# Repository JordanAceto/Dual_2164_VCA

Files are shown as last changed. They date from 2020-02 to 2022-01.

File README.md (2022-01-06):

# SSI2164 based dual VCA PCB



## [SCHEMATIC](https://github.com/JordanAceto/Dual_2164_VCA/blob/master/main_pcb/construction_docs/dual_VCA_schematic.pdf)

## Features:
- Two independent linear VCAs
- Manual offset controls
- Attenuated CV inputs
- Unity gain at +5 volts CV
- AC/DC coupling selected by solder jumper
- Designed to either use board mounted pots and jacks which affix directly to a panel, or mount to a bracket and wire by hand
- There is a 10hp pcb front panel, for a cheap and cheerful panel option.

## Status of the project:

Task | Status |
---------|--------------|
Schematic capture | &#9745;
PCB layout | &#9745;
Test build | &#9745;
Safe to order boards| &#9745;

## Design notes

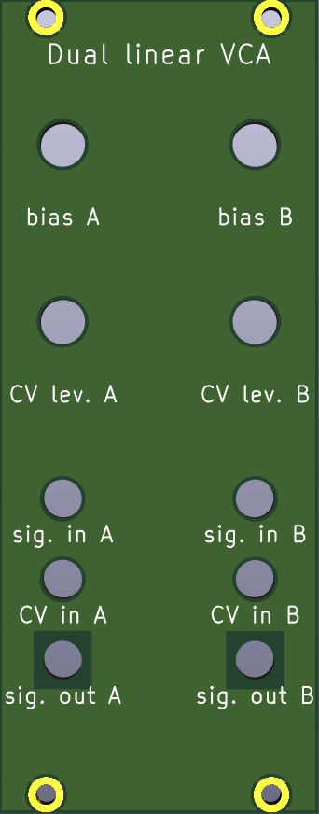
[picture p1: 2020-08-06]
front_panel/pics/front_panel.png

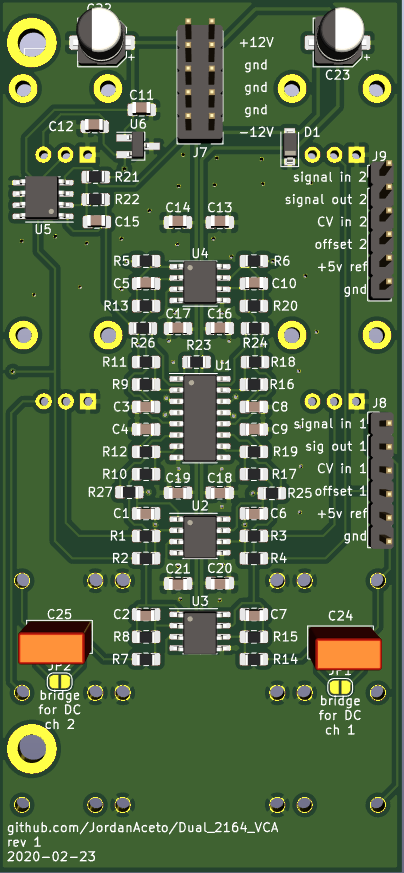
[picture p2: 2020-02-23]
main_pcb/pics/pcb_rear.png

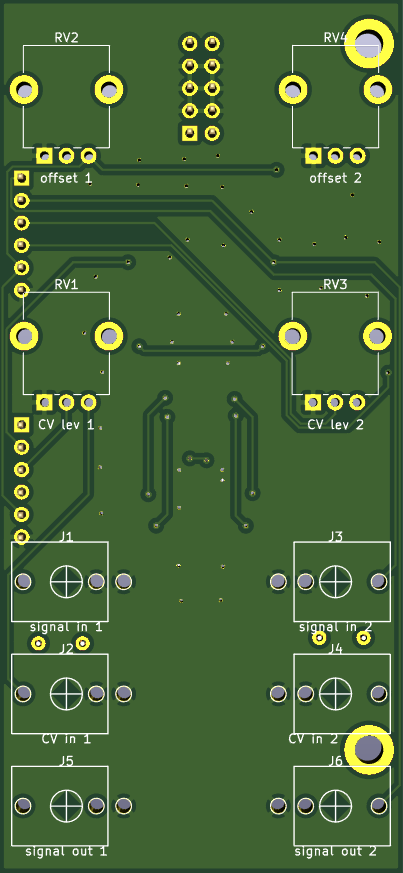
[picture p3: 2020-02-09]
main_pcb/pics/pcb_front.png

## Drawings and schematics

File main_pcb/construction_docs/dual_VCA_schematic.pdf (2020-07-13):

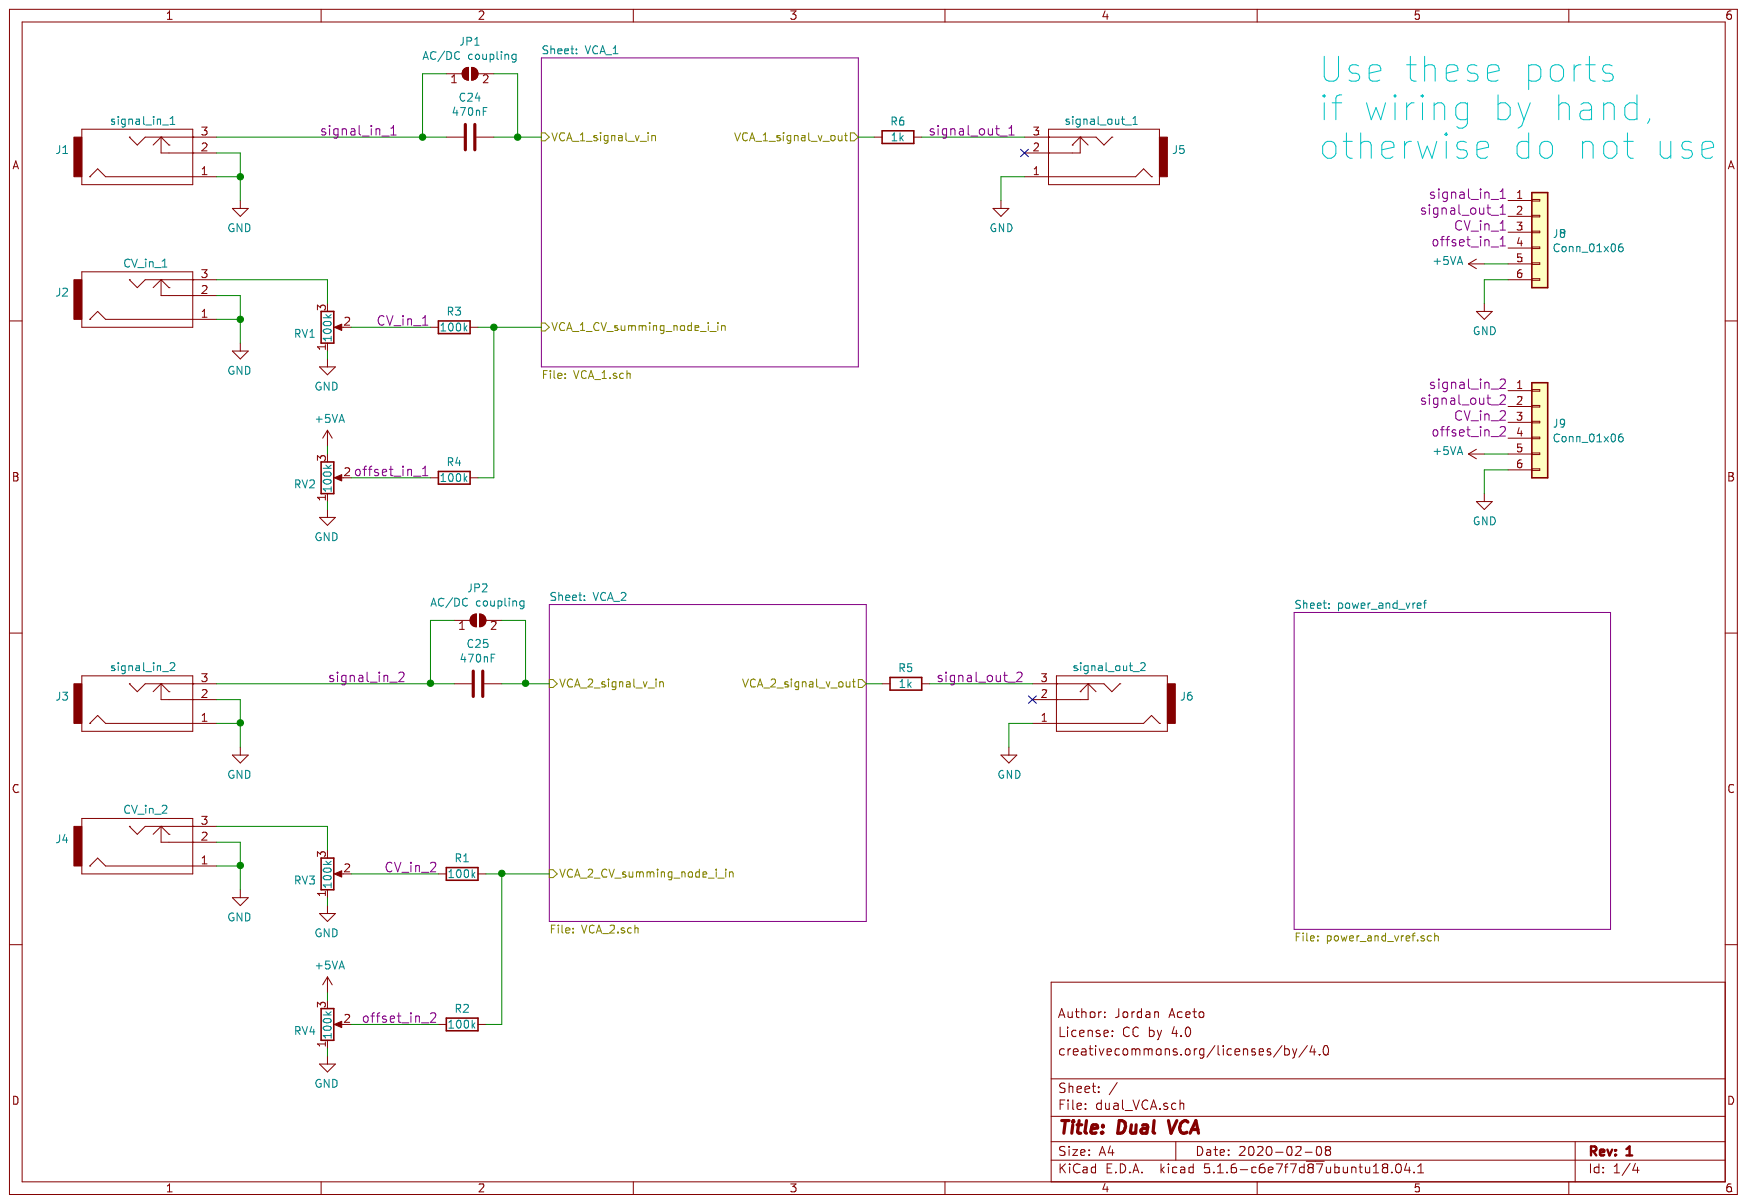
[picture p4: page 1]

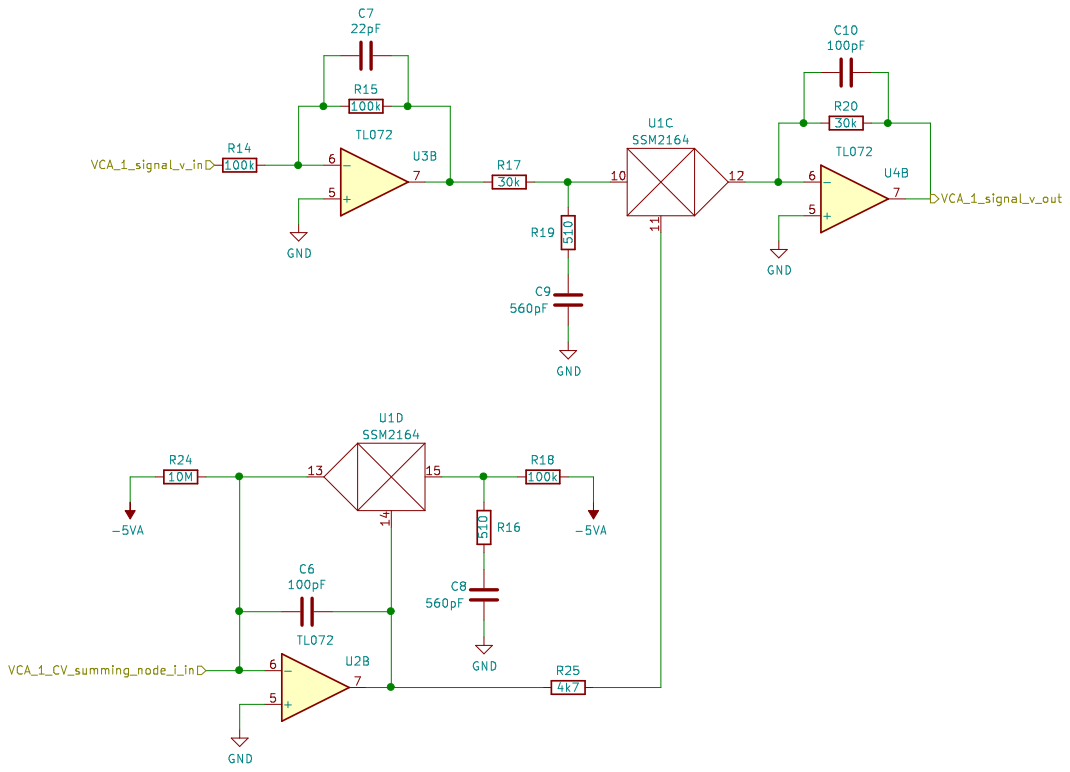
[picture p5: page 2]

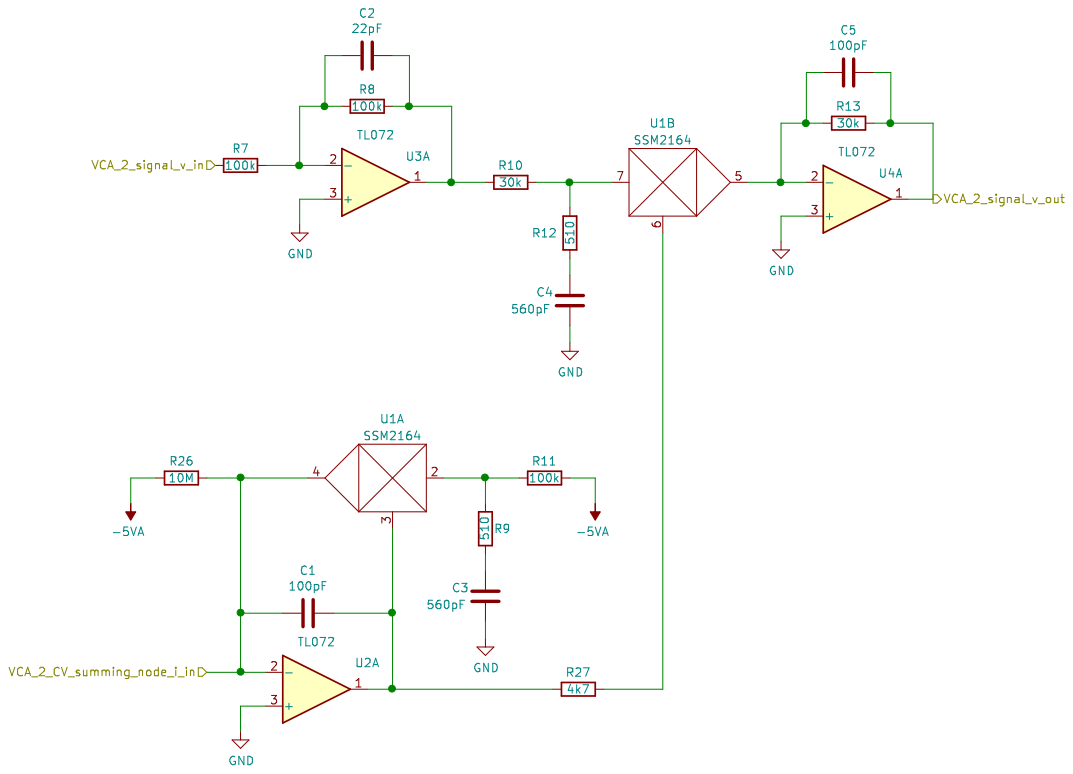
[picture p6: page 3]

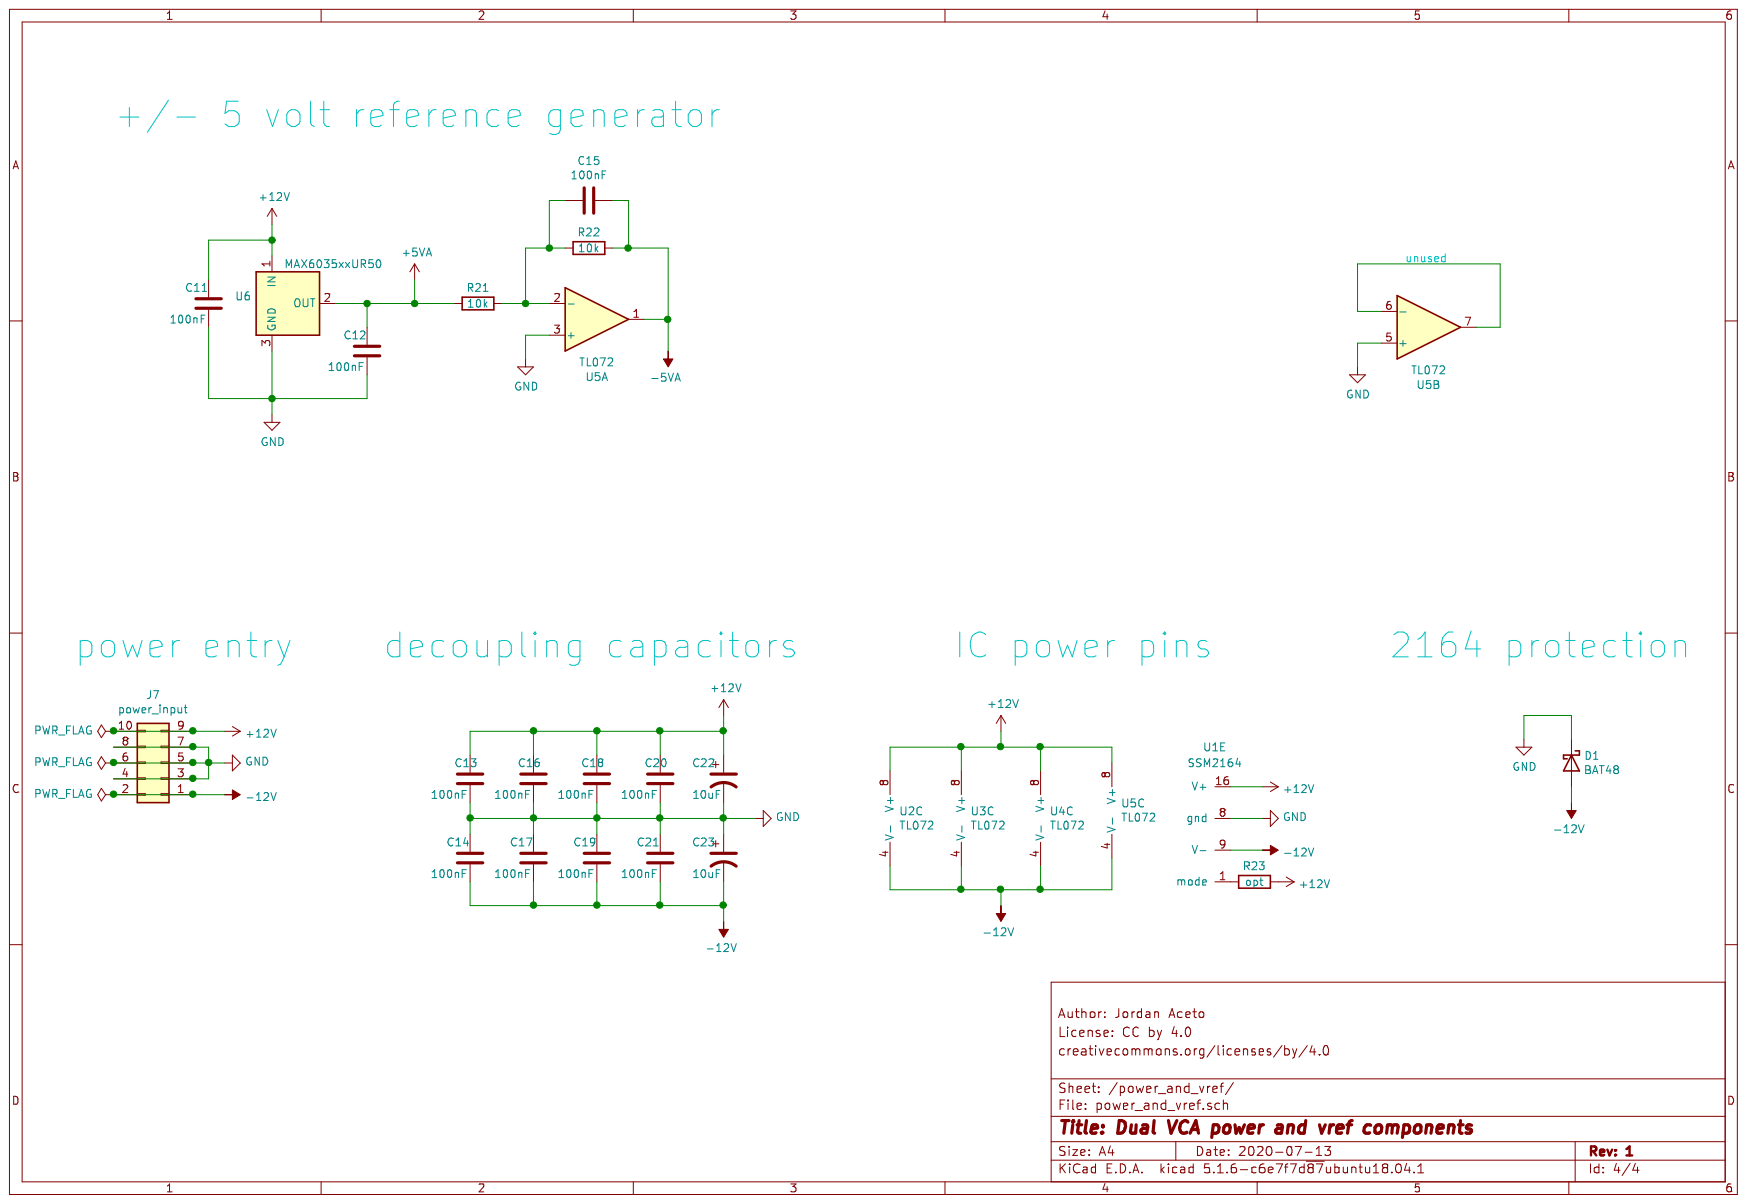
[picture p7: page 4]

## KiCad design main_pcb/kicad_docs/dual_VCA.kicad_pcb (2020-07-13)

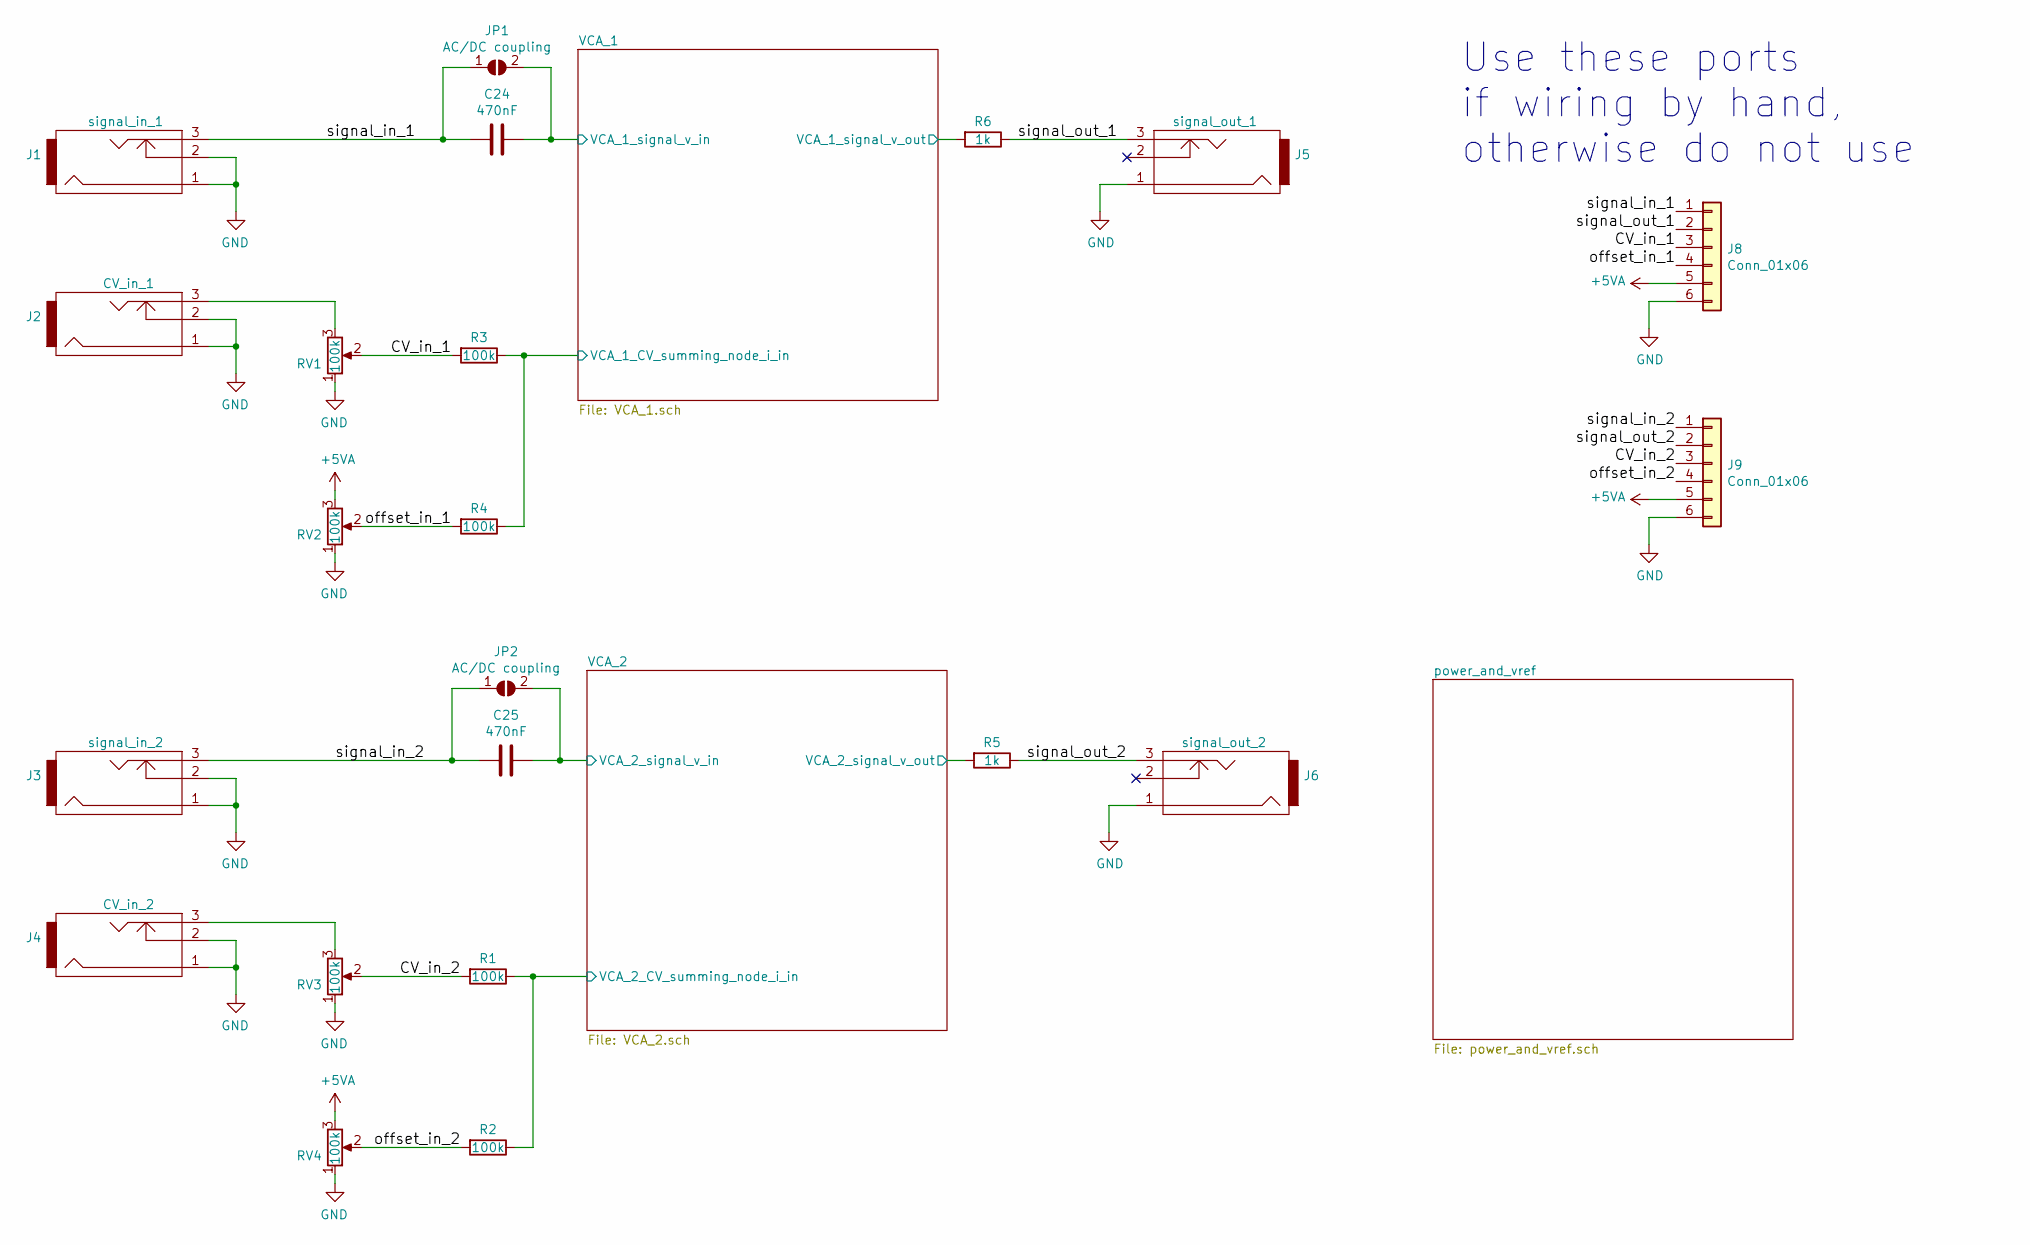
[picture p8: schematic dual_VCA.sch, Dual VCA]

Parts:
C24, C25: 470nF; C_Rect_L7.2mm_W3.5mm_P5.00mm_FKS2_FKP2_MKS2_MKP2
J1: signal_in_1; PJ301M-12
J2: CV_in_1; PJ301M-12
J3: signal_in_2; PJ301M-12
J4: CV_in_2; PJ301M-12
J5: signal_out_1; PJ301M-12
J6: signal_out_2; PJ301M-12
J8, J9: Conn_01x06; PinHeader_1x06_P2.54mm_Vertical
JP1, JP2: AC/DC coupling; SolderJumper-2_P1.3mm_Open_RoundedPad1.0x1.5mm
R1, R2, R3, R4: 100k; R_0805_2012Metric_Pad1.15x1.40mm_HandSolder
R5, R6: 1k; R_0805_2012Metric_Pad1.15x1.40mm_HandSolder
RV1, RV2, RV3, RV4: 100k; Potentiometer_Alpha_RD901F-40-00D_Single_Vertical_CircularH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

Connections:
+5VA: J8.5, J9.5, RV2.3, RV4.3; also elsewhere on the board
/CV_in_1: J8.3, R3.2, RV1.2
/CV_in_2: J9.3, R1.2, RV3.2
/VCA_1/VCA_1_CV_summing_node_i_in: R3.1, R4.1; also elsewhere on the board
/VCA_1/VCA_1_signal_v_in: C24.1, JP1.2 (B); also elsewhere on the board
/VCA_1/VCA_1_signal_v_out: R6.2; also elsewhere on the board
/VCA_2/VCA_2_CV_summing_node_i_in: R1.1, R2.1; also elsewhere on the board
/VCA_2/VCA_2_signal_v_in: C25.1, JP2.2 (B); also elsewhere on the board
/VCA_2/VCA_2_signal_v_out: R5.2; also elsewhere on the board
/offset_in_1: J8.4, R4.2, RV2.2
/offset_in_2: J9.4, R2.2, RV4.2
/signal_in_1: C24.2, J1.3, J8.1, JP1.1 (A)
/signal_in_2: C25.2, J3.3, J9.1, JP2.1 (A)
/signal_out_1: J5.3, J8.2, R6.1
/signal_out_2: J6.3, J9.2, R5.1
GND: J1.1, J1.2, J2.1, J2.2, J3.1, J3.2, J4.1, J4.2, J5.1, J6.1, J8.6, J9.6, RV1.1, RV2.1, RV3.1, RV4.1; also elsewhere on the board
unnamed: J2.3, RV1.3
unnamed: J4.3, RV3.3

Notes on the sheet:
Use these ports if wiring by hand, otherwise do not use

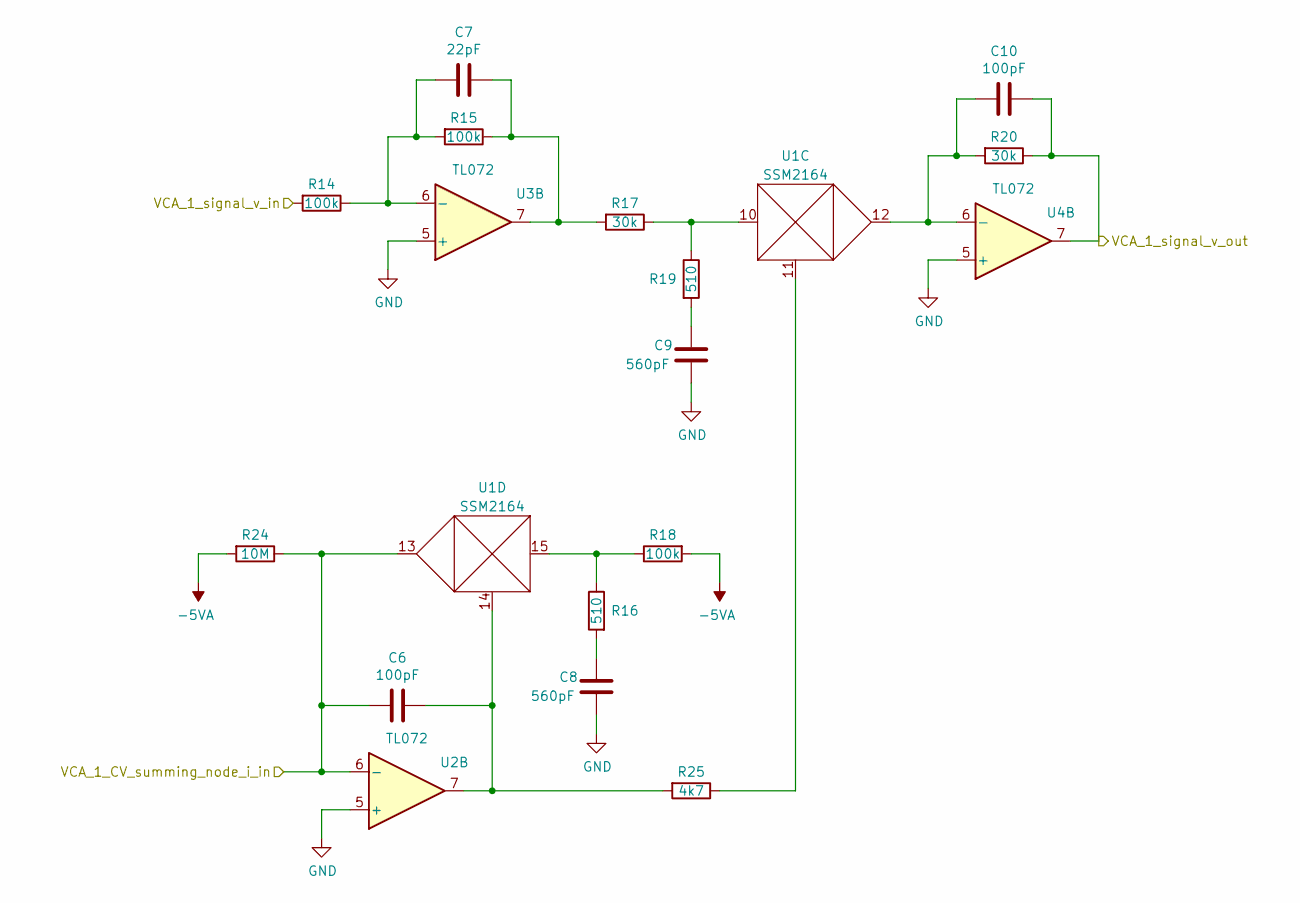
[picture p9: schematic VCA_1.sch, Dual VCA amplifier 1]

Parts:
C6, C10: 100pF; C_0805_2012Metric_Pad1.15x1.40mm_HandSolder
C7: 22pF; C_0805_2012Metric_Pad1.15x1.40mm_HandSolder
C8, C9: 560pF; C_0805_2012Metric_Pad1.15x1.40mm_HandSolder
R14, R15, R18: 100k; R_0805_2012Metric_Pad1.15x1.40mm_HandSolder
R16, R19: 510; R_0805_2012Metric_Pad1.15x1.40mm_HandSolder
R17, R20: 30k; R_0805_2012Metric_Pad1.15x1.40mm_HandSolder
R24: 10M; R_0805_2012Metric_Pad1.15x1.40mm_HandSolder
R25: 4k7; R_0805_2012Metric_Pad1.15x1.40mm_HandSolder
U1: SSM2164; SOIC-16_3.9x9.9mm_P1.27mm
U2, U3, U4: TL072; SOIC-8_3.9x4.9mm_P1.27mm

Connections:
-5VA: R18.2, R24.2; also elsewhere on the board
/VCA_1/VCA_1_CV_summing_node_i_in: C6.2, R24.1, U1.13, U2.6 (-); also elsewhere on the board
/VCA_1/VCA_1_signal_v_in: R14.2; also elsewhere on the board
/VCA_1/VCA_1_signal_v_out: C10.1, R20.1, U4.7; also elsewhere on the board
GND: C8.2, C9.2, U2.5 (+), U3.5 (+), U4.5 (+); also elsewhere on the board
unnamed: C6.1, R25.2, U1.14, U2.7
unnamed: C7.1, R15.1, R17.2, U3.7
unnamed: C7.2, R14.1, R15.2, U3.6 (-)
unnamed: C8.1, R16.2
unnamed: C9.1, R19.2
unnamed: C10.2, R20.2, U1.12, U4.6 (-)
unnamed: R16.1, R18.1, U1.15
unnamed: R17.1, R19.1, U1.10
unnamed: R25.1, U1.11

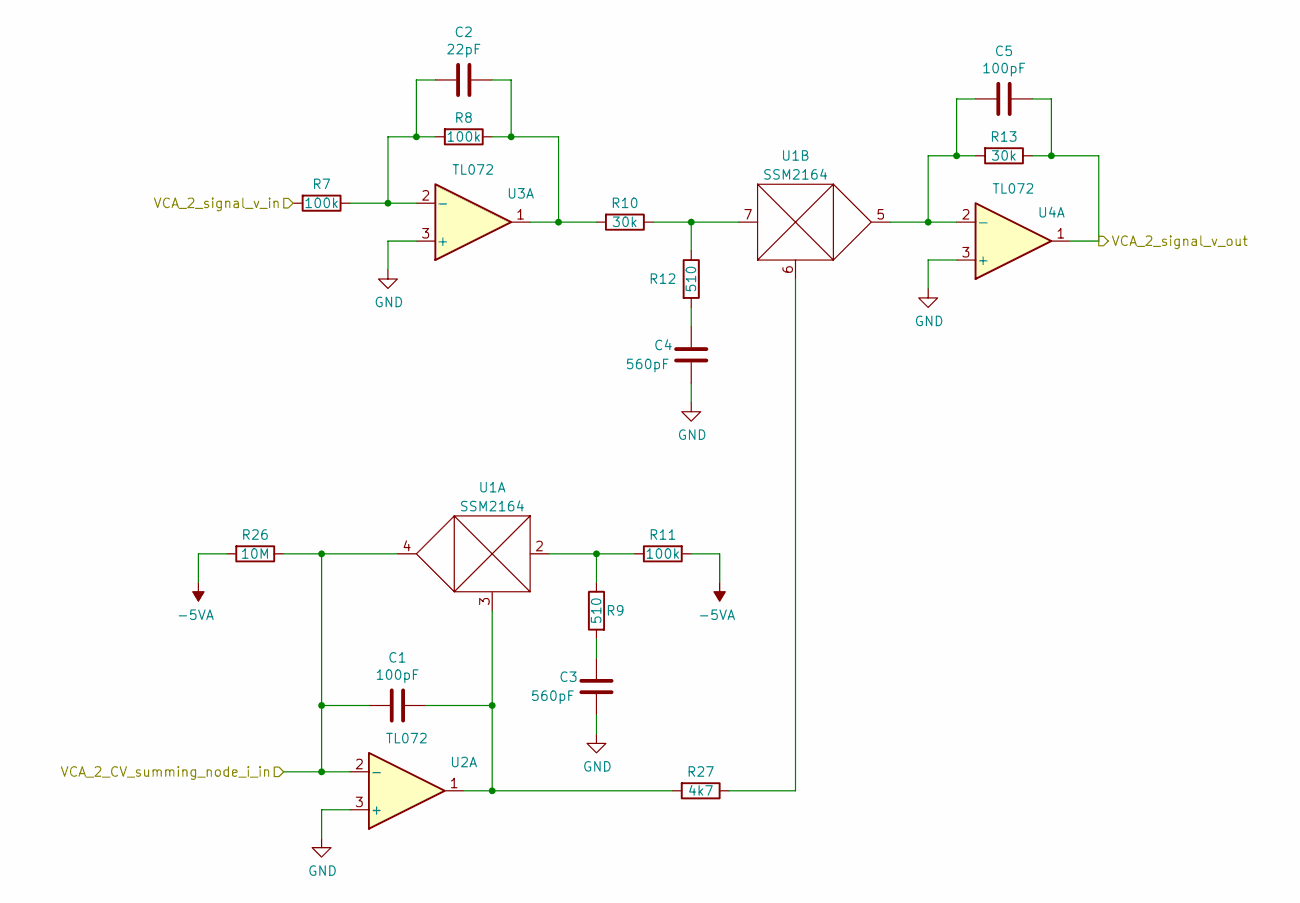
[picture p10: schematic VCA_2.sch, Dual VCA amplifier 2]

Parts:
C1, C5: 100pF; C_0805_2012Metric_Pad1.15x1.40mm_HandSolder
C2: 22pF; C_0805_2012Metric_Pad1.15x1.40mm_HandSolder
C3, C4: 560pF; C_0805_2012Metric_Pad1.15x1.40mm_HandSolder
R7, R8, R11: 100k; R_0805_2012Metric_Pad1.15x1.40mm_HandSolder
R9, R12: 510; R_0805_2012Metric_Pad1.15x1.40mm_HandSolder
R10, R13: 30k; R_0805_2012Metric_Pad1.15x1.40mm_HandSolder
R26: 10M; R_0805_2012Metric_Pad1.15x1.40mm_HandSolder
R27: 4k7; R_0805_2012Metric_Pad1.15x1.40mm_HandSolder
U1: SSM2164; SOIC-16_3.9x9.9mm_P1.27mm
U2, U3, U4: TL072; SOIC-8_3.9x4.9mm_P1.27mm

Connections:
-5VA: R11.2, R26.2; also elsewhere on the board
/VCA_2/VCA_2_CV_summing_node_i_in: C1.2, R26.1, U1.4, U2.2 (-); also elsewhere on the board
/VCA_2/VCA_2_signal_v_in: R7.2; also elsewhere on the board
/VCA_2/VCA_2_signal_v_out: C5.1, R13.1, U4.1; also elsewhere on the board
GND: C3.2, C4.2, U2.3 (+), U3.3 (+), U4.3 (+); also elsewhere on the board
unnamed: C1.1, R27.2, U1.3, U2.1
unnamed: C2.1, R8.1, R10.2, U3.1
unnamed: C2.2, R7.1, R8.2, U3.2 (-)
unnamed: C3.1, R9.2
unnamed: C4.1, R12.2
unnamed: C5.2, R13.2, U1.5, U4.2 (-)
unnamed: R10.1, R12.1, U1.7
unnamed: R9.1, R11.1, U1.2
unnamed: R27.1, U1.6

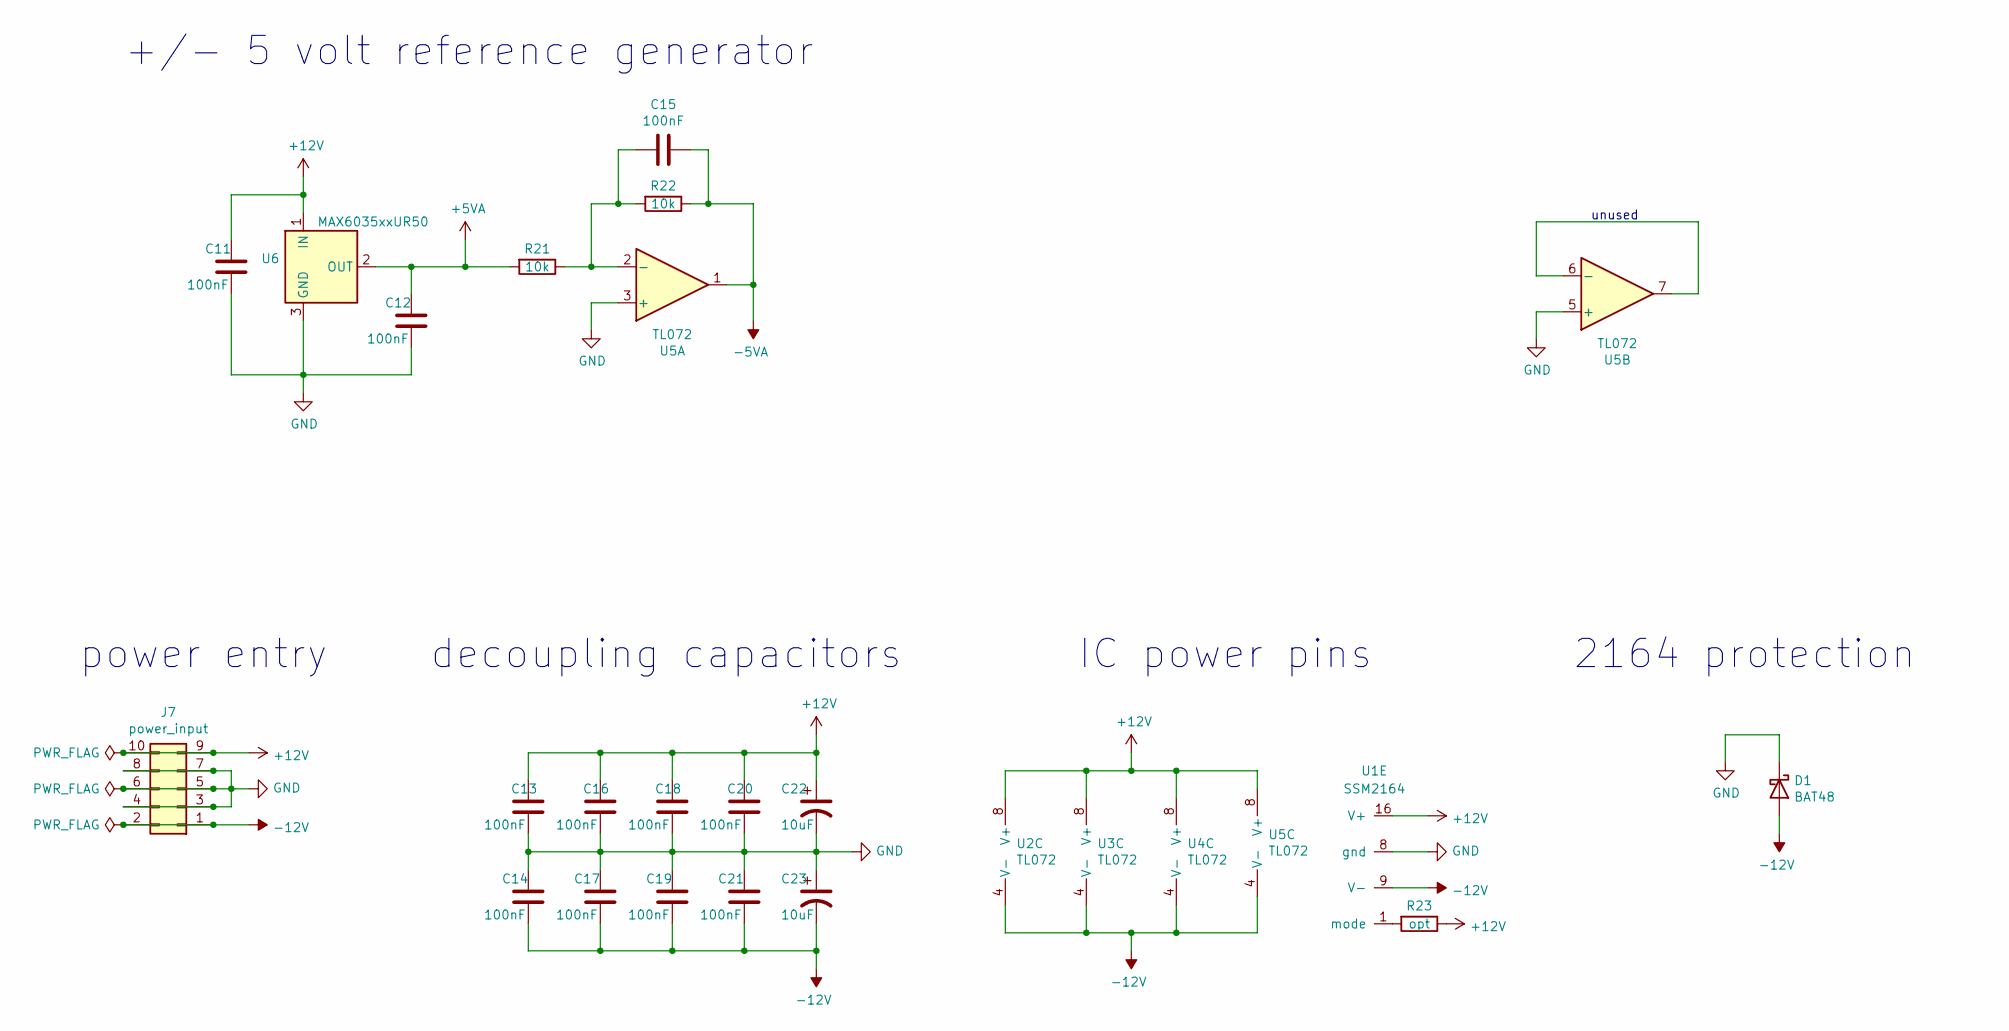
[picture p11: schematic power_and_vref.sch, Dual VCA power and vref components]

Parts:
C11, C12, C13, C14, C15, C16, C17, C18, C19, C20, C21: 100nF; C_0805_2012Metric_Pad1.15x1.40mm_HandSolder
C22, C23: 10uF; CP_Elec_5x5.4
D1: BAT48; D_SOD-123
J7: power_input; PinHeader_2x05_P2.54mm_Vertical
R21, R22: 10k; R_0805_2012Metric_Pad1.15x1.40mm_HandSolder
R23: opt; R_0805_2012Metric_Pad1.15x1.40mm_HandSolder
U1: SSM2164; SOIC-16_3.9x9.9mm_P1.27mm
U2, U3, U4, U5: TL072; SOIC-8_3.9x4.9mm_P1.27mm
U6: MAX6035xxUR50; SOT-23_Handsoldering

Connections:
+5VA: C12.1, R21.2, U6.2 (OUT); also elsewhere on the board
+12V: C11.1, C13.1, C16.1, C18.1, C20.1, C22.1, J7.9, J7.10, R23.1, U1.16 (V+), U2.8 (V+), U3.8 (V+), U4.8 (V+), U5.8 (V+), U6.1 (IN)
-5VA: C15.1, R22.1, U5.1; also elsewhere on the board
-12V: C14.2, C17.2, C19.2, C21.2, C23.2, D1.2 (A), J7.1, J7.2, U1.9 (V-), U2.4 (V-), U3.4 (V-), U4.4 (V-), U5.4 (V-)
GND: C11.2, C12.2, C13.2, C14.1, C16.2, C17.1, C18.2, C19.1, C20.2, C21.1, C22.2, C23.1, D1.1 (K), J7.3, J7.4, J7.5, J7.6, J7.7, J7.8, U1.8 (gnd), U5.3 (+), U5.5 (+), U6.3 (GND); also elsewhere on the board
unnamed: C15.2, R21.1, R22.2, U5.2 (-)
unnamed: R23.2, U1.1 (mode)
unnamed: U5.6 (-), U5.7

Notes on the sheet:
unused
decoupling capacitors
IC power pins
+/- 5 volt reference generator
power entry
2164 protection

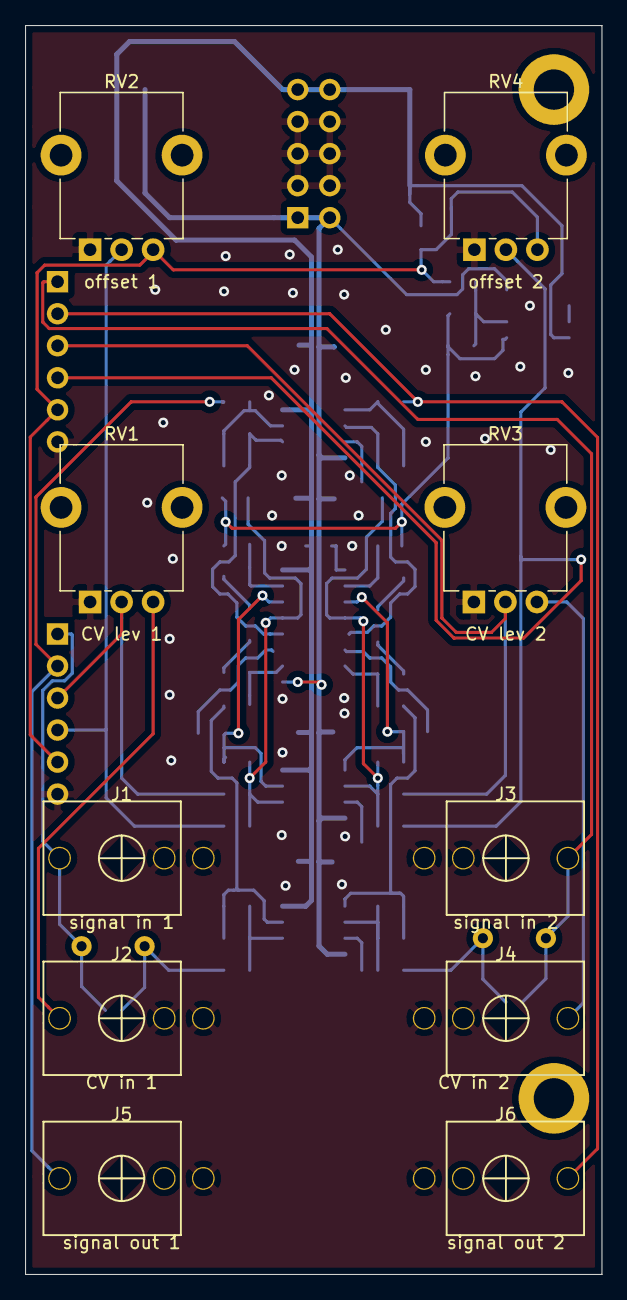
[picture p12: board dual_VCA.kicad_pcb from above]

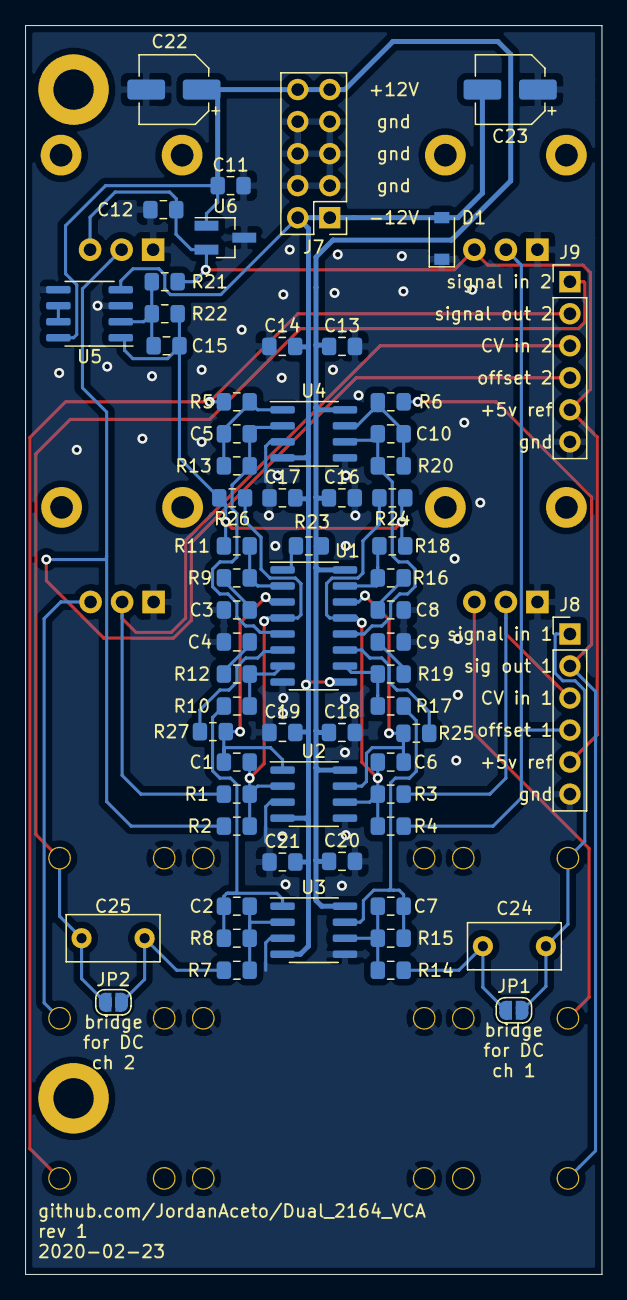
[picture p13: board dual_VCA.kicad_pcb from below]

Board: 2 copper layers, 45.7 x 99.1 mm, 74 parts (64 on the bottom side), 42 nets.

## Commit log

2020-02-09 add AC/DC coupling caps and jumper
    [VCA_1.sch, VCA_2.sch, dual_VCA.kicad_pcb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]
2020-02-09 update pics to reflect AC/DC coupling
2020-02-09 add values to r's, add r's to CV circuit
    [VCA_1.sch, VCA_2.sch, dual_VCA.kicad_pcb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]
2020-02-09 update pcb png's
2020-02-09 add schematic pdf
2020-02-23 add github url to pcb silkscreen
    [dual_VCA.kicad_pcb]
2020-07-13 add panel, generate interactive BOM
    [VCA_1.sch, VCA_2.sch, dual_VCA.kicad_pcb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]
2020-08-06 add front panel, update readme
    [front_panel-B_Cu.gbr, front_panel-B_Mask.gbr, front_panel-B_SilkS.gbr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]
2021-12-09 reorganize pics and readmes
    [VCA_1.sch, VCA_2.sch, dual_VCA.kicad_pcb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]
2022-01-06 give schematic better name

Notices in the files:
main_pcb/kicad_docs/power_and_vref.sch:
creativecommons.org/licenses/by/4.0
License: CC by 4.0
